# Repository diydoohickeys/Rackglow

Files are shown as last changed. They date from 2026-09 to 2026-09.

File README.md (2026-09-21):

# Rackglow

**An audio-reactive lighting controller for a modular synth case.** A 3.5" touchscreen on the
front panel, WS2812 strips behind the rails, and a spectrum analyser listening to the case's
output — so the lights move with whatever you're patching. Control it from the screen, from a
browser, or from Home Assistant.

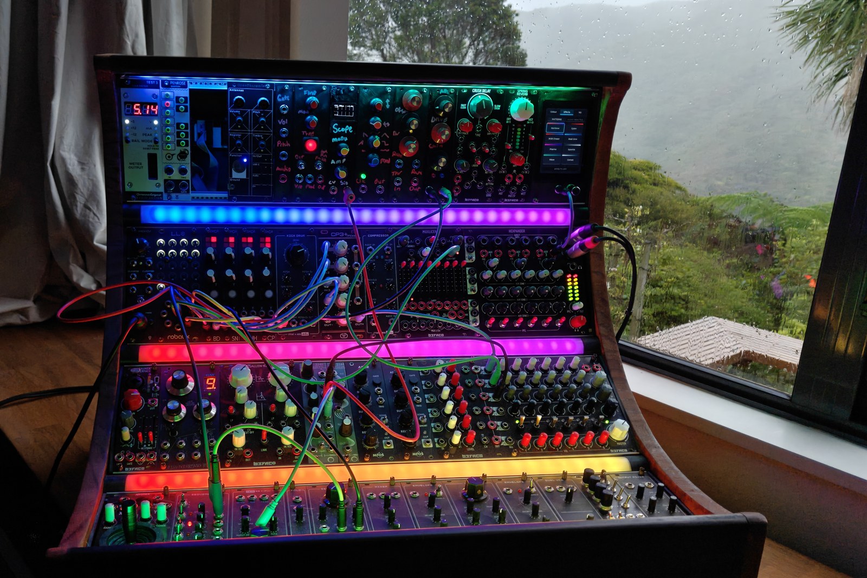
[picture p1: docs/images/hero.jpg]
Rackglow lighting a modular synth case, the strips running a multi-colour effect


https://github.com/user-attachments/assets/42361cac-358a-4347-8153-37f31353e51d

## Features

- **Colour, white and effects** — a colour wheel, a white mode, and 17 effects, 7 of them
  audio-reactive (marked **(A)**: Ice Waves, Purple Rain, Fire, Matrix, VU, Ripple, Confetti).
- **Audio-reactive** — an MSGEQ7 seven-band spectrum analyser drives the (A) effects and a VU mode
  that pumps the strip brightness with the level.
- **Touchscreen UI** — three swipeable tabs: Colour, Effects and a live VU meter.
- **Screensaver** — after an idle timeout the screen hands over to one of five full-screen
  visuals (VU Meter, Waterfall, Aurora, Bloom, Rings); swipe to change, tap to dismiss.
- **Web UI** — the same controls from any browser on your network, plus LED, screensaver and
  Home Assistant settings.
- **Home Assistant** — appears automatically over MQTT as a light (colour, brightness, effects) with
  VU Mode and Screen Sleep switches. No custom integration needed.
- **Screen Sleep** — turn the screen fully off from Home Assistant; tap it to wake.
- **Updates over WiFi** — WiFi setup, a log viewer and firmware updates come from
  [Preflight](https://github.com/diydoohickeys/Preflight-Arduino).

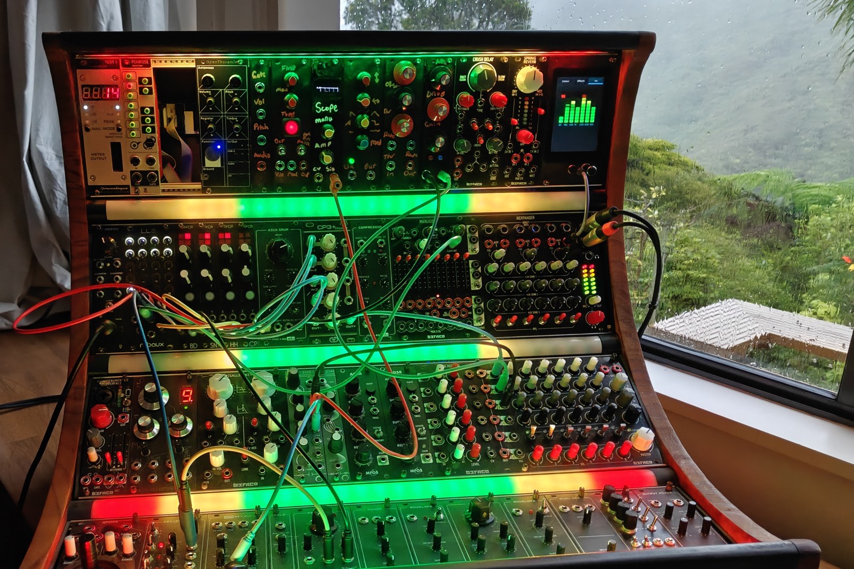
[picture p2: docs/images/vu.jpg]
VU mode running: the strips tracking the case's output, green through red


| Colour | Effects | VU |
|---|---|---|
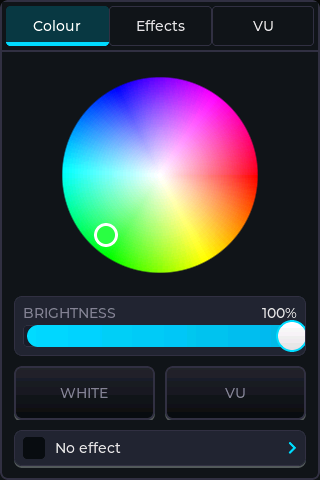
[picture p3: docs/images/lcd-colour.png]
Colour tab
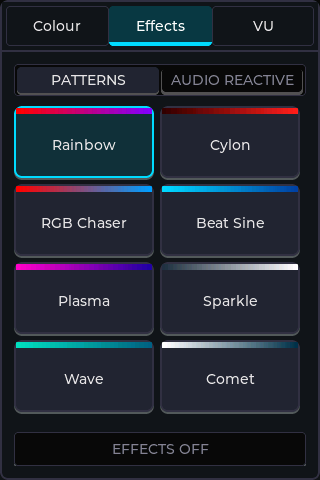
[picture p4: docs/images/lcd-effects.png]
Effects tab
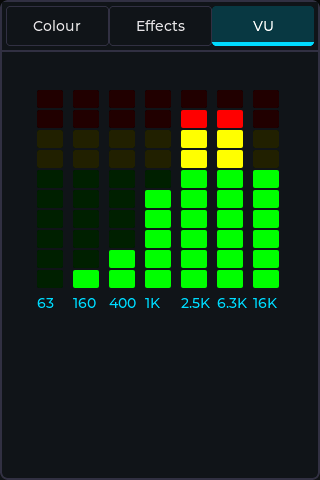
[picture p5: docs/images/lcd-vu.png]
VU tab
|  |  |  |

| VU Meter | Waterfall | Aurora | Bloom | Rings |
|---|---|---|---|---|
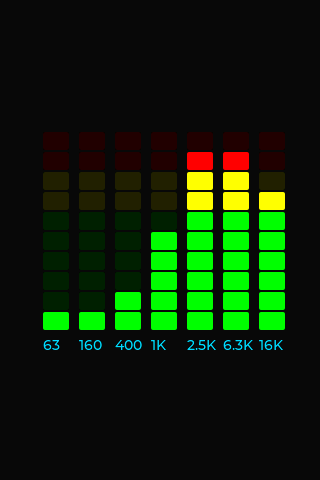
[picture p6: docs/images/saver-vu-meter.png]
VU Meter
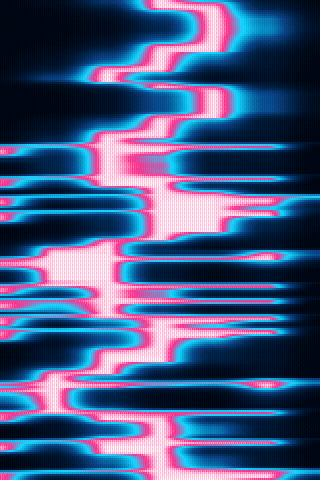
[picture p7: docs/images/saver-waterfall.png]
Waterfall
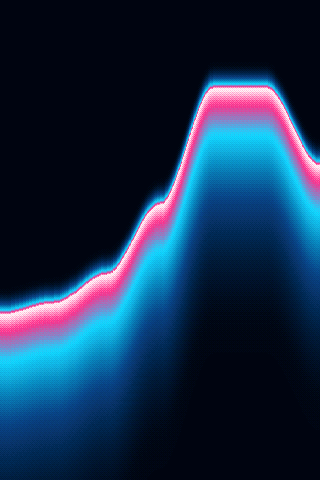
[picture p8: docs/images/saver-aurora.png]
Aurora
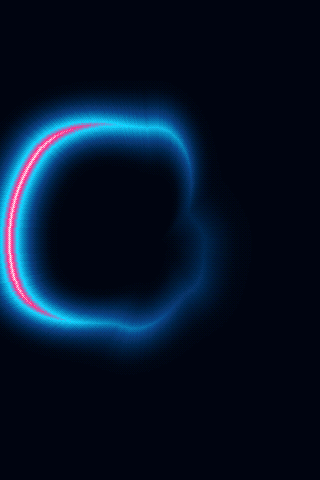
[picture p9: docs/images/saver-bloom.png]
Bloom
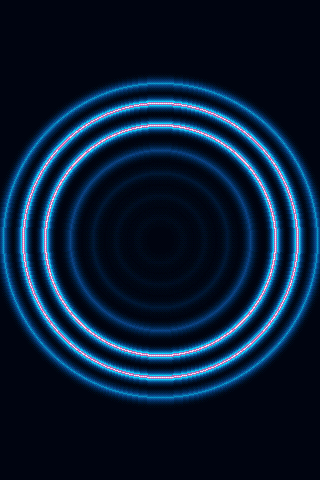
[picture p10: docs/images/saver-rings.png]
Rings
|  |  |  |  |  |

## Hardware

Everything sits behind a 3D-printed panel: the board, and a scrap of protoboard carrying an MSGEQ7
and a handful of passives. There's no custom PCB to order. The panel's CAD and printable files are
in [`hardware/printed/`](hardware/printed) — four parts as STLs, a STEP and the Fusion source.
Standard slicer defaults; only the plug cover needs supports.

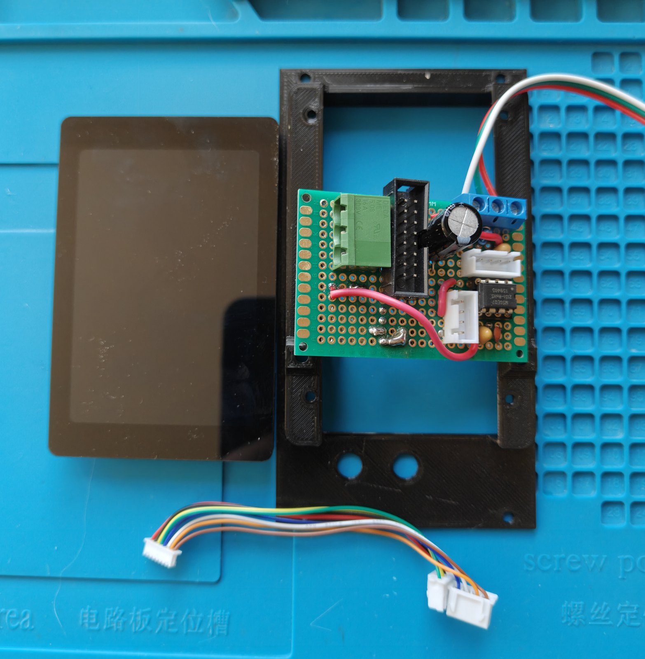
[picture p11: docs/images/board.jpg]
The board, the protoboard and the printed panel, before assembly


| Part | Qty | Notes |
|---|---|---|
| [WT32-SC01 Plus](https://en.wireless-tag.com/product-item-26.html) | 1 | ESP32-S3, 8 MB flash, QSPI PSRAM, 3.5" 320×480 ST7796 touchscreen |
| MSGEQ7 | 1 | Seven-band graphic equaliser, DIP-8. A socket is worth it |
| WS2812 / WS2812B strips | — | Equal-length strips on one data line. The builds here are 5 × 29 and 3 × 29 LEDs |
| A10k potentiometer | 1 | Front-panel input attenuator (audio taper) |
| 3.5 mm jack | 1 | Audio in |
| 22 kΩ, 330 Ω resistors | 1 each | Audio input; WS2812 data line |
| 200 kΩ resistor | 1 | MSGEQ7 clock |
| 0.01 µF, 33 pF, 2 × 0.1 µF | | MSGEQ7 input, clock and decoupling |
| 1000 µF electrolytic, 6.3 V+ | 1 | Across 5 V at the LED terminal |
| Screw terminals, 2- and 3-way | 1 each | 5 V input; LED output |
| 10-pin IDC header | 1 | Eurorack bus power (optional, see below) |
| Protoboard, hook-up wire, JST connectors | | |
| 3D-printed parts | 4 | Panel, LED holder and two covers: [`hardware/printed/`](hardware/printed) |
| 5 V supply for the strips | 1 | Roughly 60 mA per LED at full white. Separate from the case's Eurorack supply |

### Wiring

Wiring diagram

Everything connects to the board's **Extended IO header**, which also carries +5 V and GND. These
are the only GPIOs the WT32-SC01 Plus breaks out; the rest drive the display and touch.

| Header pin | GPIO | Connect to |
|---|---|---|
| EXT_IO1 | 10 | WS2812 data, through the 330 Ω resistor |
| EXT_IO3 | 12 | MSGEQ7 OUT (pin 3) |
| EXT_IO4 | 13 | MSGEQ7 STROBE (pin 4) |
| EXT_IO6 | 21 | MSGEQ7 RESET (pin 7) |
| EXT_IO2, EXT_IO5 | 11, 14 | free |

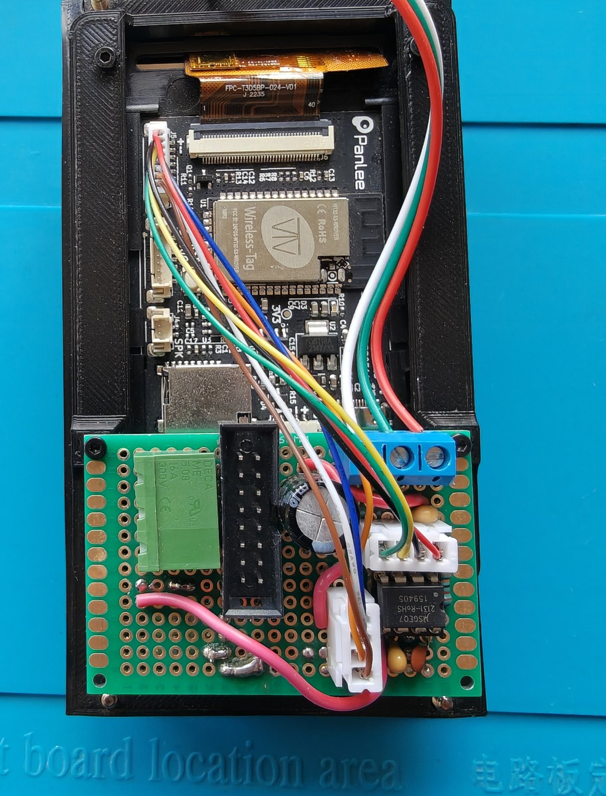
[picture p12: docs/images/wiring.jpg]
The loom from the Extended IO header down to the MSGEQ7 protoboard


**The MSGEQ7 circuit is the datasheet's Typical Application**, unchanged: 22 kΩ and 0.01 µF into IN,
0.1 µF on VDD, another 0.1 µF on pin 6 (the chip's internal 2.5 V reference), and the clock set by
200 kΩ from CKIN up to VDD with 33 pF from CKIN down to ground. Full schematic:
[`hardware/rackglow.pdf`](hardware/rackglow.pdf), editable in KiCad as
[`hardware/rackglow.kicad_sch`](hardware/rackglow.kicad_sch).

**Audio in.** The jack takes a Eurorack-level signal — an FX send, in this build — which is around
10 Vpp, while the MSGEQ7 wants roughly 0.1–0.3 Vpp. The front-panel pot does that attenuation: turn
it up until the loudest passage just reaches the top band without pinning, then back off slightly.
Line level works too, with the pot further up.

**Power.** The panel and the strips are fed separately — the panel draws very little, the strips
draw a lot.

| | Feeds | Notes |
|---|---|---|
| J3 · Eurorack 10-pin bus header | the panel | +5 V and GND from the case's bus board |
| J4 · 5 V screw terminal | the panel, the strips, or both | An external supply |

⚠ **Don't run the strips from a Eurorack 5 V rail.** 145 LEDs at full white can ask for several amps,
far more than those rails are built for. Give the strips their own 5 V supply, sized for roughly
60 mA per LED at full white, and share ground with the board.

What that looks like if you get it wrong: **oscillator pitch drifting as you turn the lights up.**
The strips load the rail, the rail sags, and everything running off it goes with it. That symptom is
what put the second supply in this build — and it reads as a synth fault, not a lighting one.

The reference build uses **two supplies**: the case's Eurorack bus powers the panel through J3, and
a second 5 V supply drives the LED strips alone. One supply through J4 works too, if it is sized for
the strips plus the board.

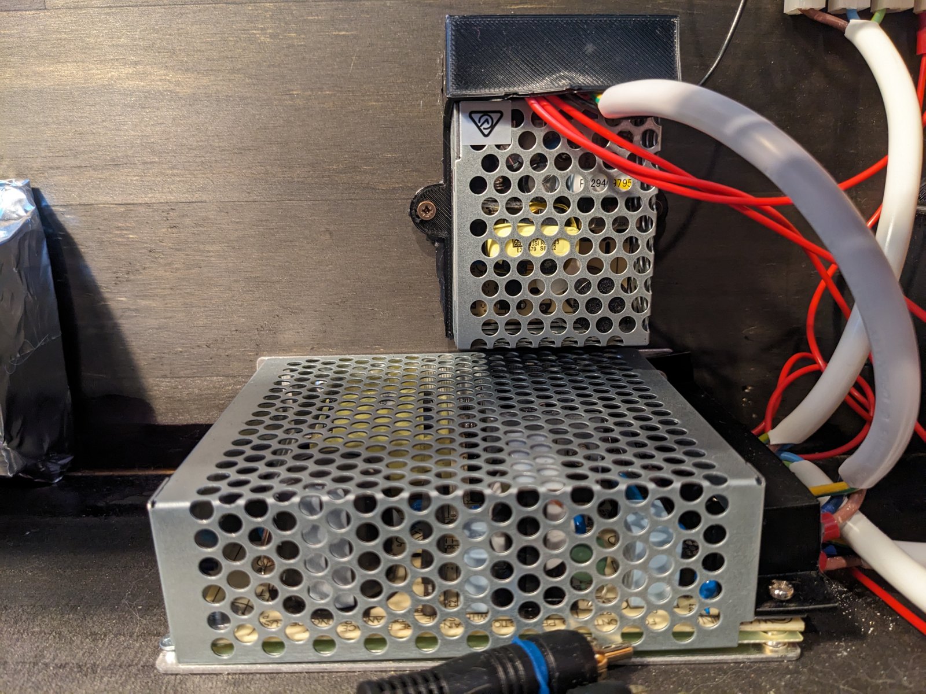
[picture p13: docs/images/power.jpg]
The case's supplies: Eurorack on top, the strips' own 5 V below


**Strip layout.** Strips are daisy-chained on the one data line and treated as equal-length rows.
Alternate strips run in opposite directions (serpentine), which is how they chain naturally behind a
rail. Set the strip count and LEDs per strip under **LED Config** in the web UI.

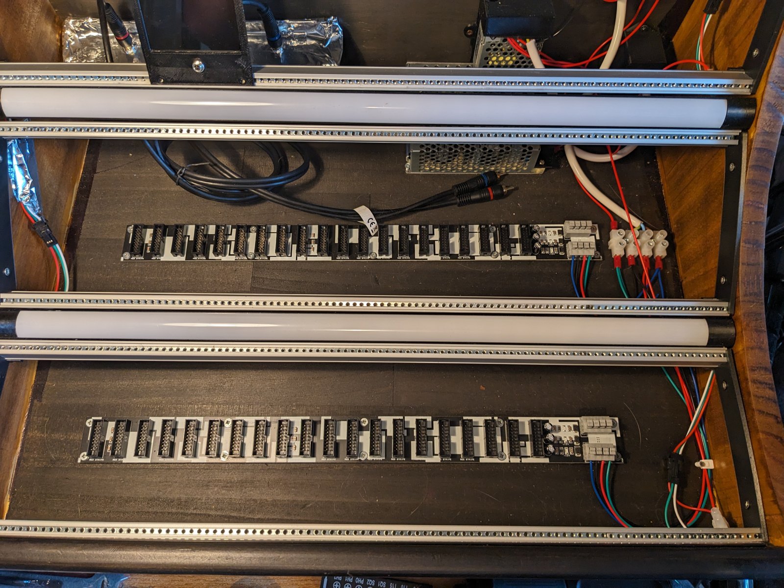
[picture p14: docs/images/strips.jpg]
Strips in aluminium channels between the rails, chained row to row


## Install

### From your browser (easiest)

1. Open **[diydoohickeys.github.io/Rackglow](https://diydoohickeys.github.io/Rackglow/)** in desktop
   Chrome or Edge. Firefox, Safari and phones don't support Web Serial.
2. Plug the board in over USB-C and click **Install**. No button to hold — the board is put into
   download mode over the USB connection.
3. The install erases the board, so it starts fresh.

### First-time setup

1. On first boot Rackglow opens a WiFi network called **`Rackglow-Setup`**
   (password `rackglow123`).
2. Join it from your phone. The setup page opens by itself; if it doesn't, browse to
   `192.168.4.1`.
3. Pick your WiFi network, enter its password and a device name, and save. Rackglow restarts and
   joins your network.
4. Open **`http://rackglow.local`** (or the IP address shown on the screen) and set the strip
   layout under **LED Config**.

### Updating

Download `firmware.bin` from the [latest release](https://github.com/diydoohickeys/Rackglow/releases/latest)
and upload it at **`http://rackglow.local/update`**. Settings are kept.

## Web UI

| Controls | Audio Reactive |
|---|---|
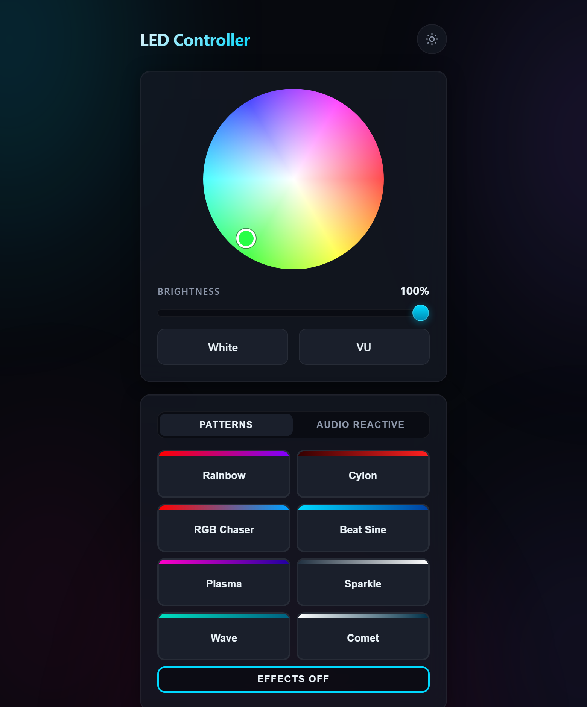
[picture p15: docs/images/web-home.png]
Web UI home
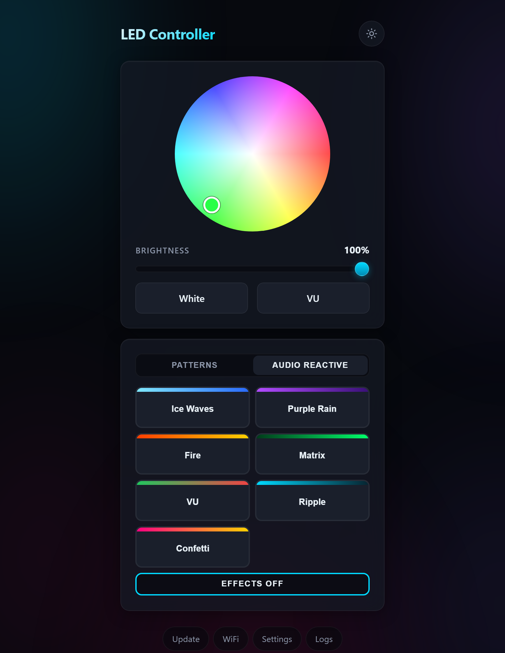
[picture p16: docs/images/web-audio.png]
Audio reactive effects
|  |  |

**LED Config** holds the strip layout, the screensaver and the Home Assistant settings, plus a
screenshot tool for the panel.

| Screensaver + Home Assistant | LED strips |
|---|---|
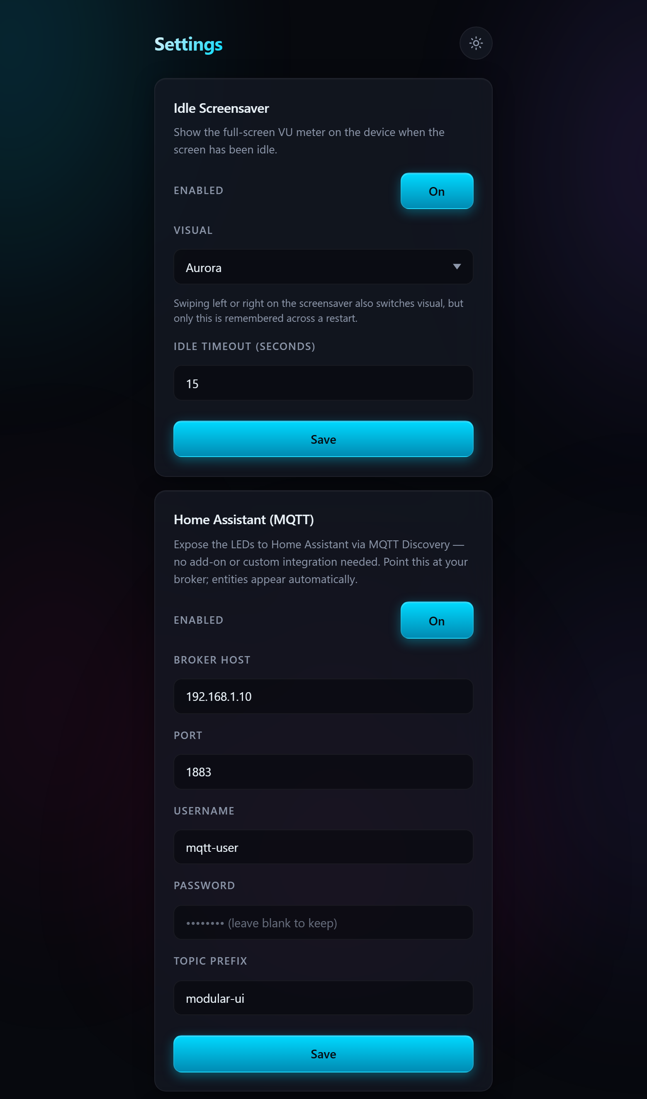
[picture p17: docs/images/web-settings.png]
Settings
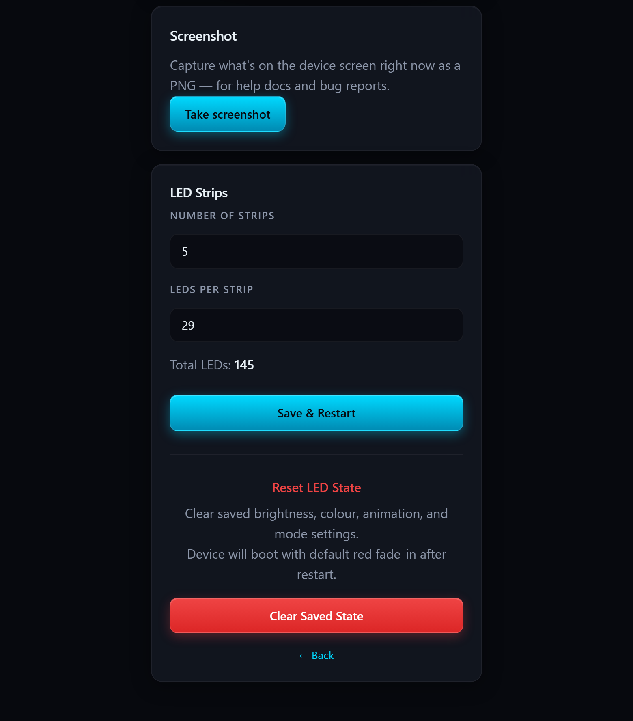
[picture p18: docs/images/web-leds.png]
LED settings
|  |  |

`http://rackglow.local/logs` shows the device log — the first place to look when something isn't
working.

## Home Assistant

Rackglow talks to Home Assistant over MQTT and announces itself using MQTT discovery. You need an
MQTT broker; if you don't already run one, use the **Mosquitto broker** app (formerly add-on).

### 1. Install the broker

In Home Assistant go to **Settings → Apps**, install **Mosquitto broker** and start it. Home
Assistant offers to set up the MQTT integration once it's running — accept it.

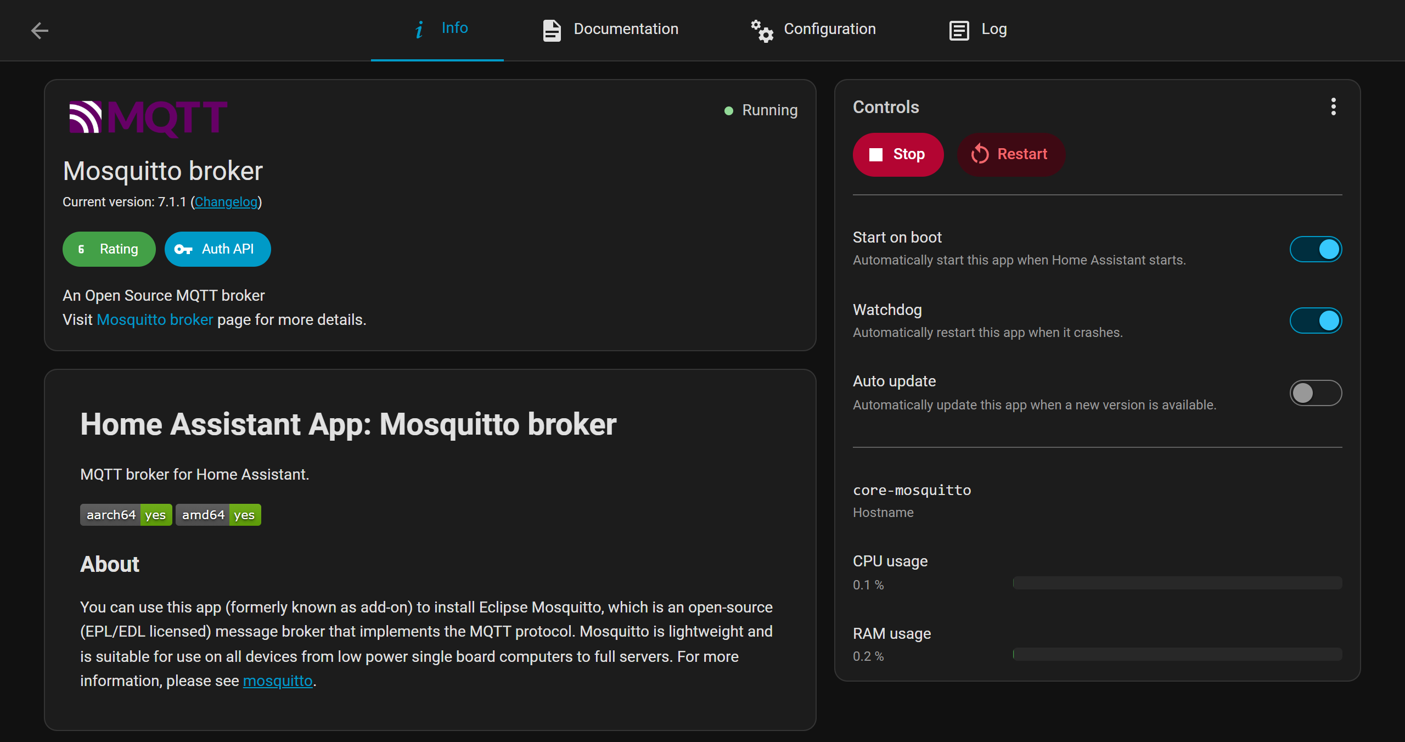
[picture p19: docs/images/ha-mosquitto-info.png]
Mosquitto broker app


### 2. Create a login for Rackglow

Give Rackglow its own broker login rather than a Home Assistant user. Rackglow stores the password
on the device, and a broker-only login can't be used to sign in to Home Assistant itself.

1. Open the Mosquitto broker's **Configuration** tab.
2. Under **Logins** click **Add**, enter a username (e.g. `rackglow`) and a password, and click
   **Add**.

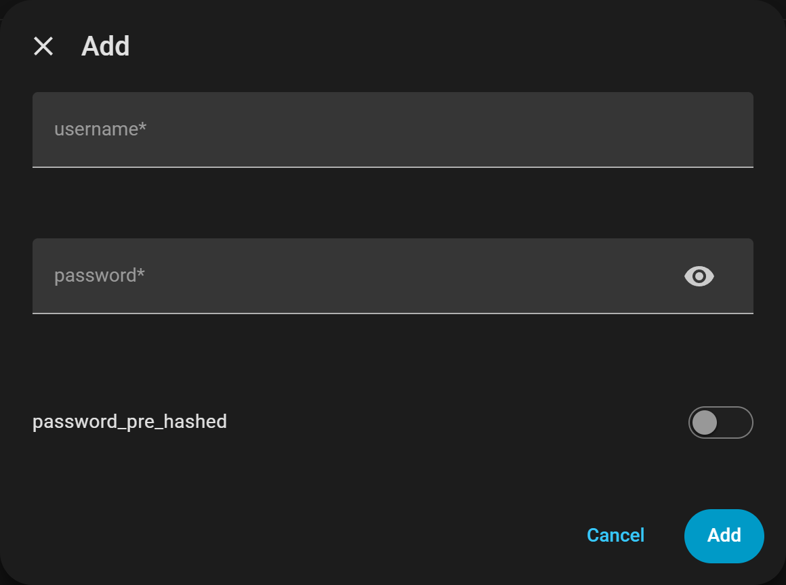
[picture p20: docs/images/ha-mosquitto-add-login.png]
Add a login
   

3. Scroll to the bottom of the **Options** card and click its **Save** — it's the button at the end
   of that card, not the one under Network. Accept the offer to restart the broker.

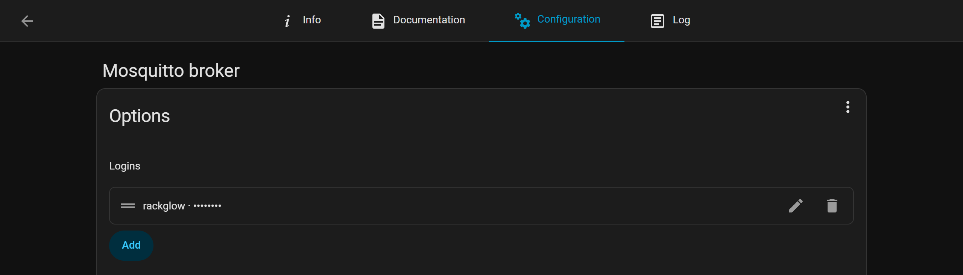
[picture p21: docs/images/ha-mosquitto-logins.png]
Saved login
   

### 3. Connect Rackglow

In Rackglow's web UI open **LED Config → Home Assistant MQTT**, set **Enabled** to On and enter:

| Field | Value |
|---|---|
| Broker Host | Your Home Assistant's IP address (e.g. `192.168.1.20`) |
| Port | `1883` |
| Username / Password | The login from step 2 |

Save. Within a few seconds Rackglow appears under **Settings → Devices & services → MQTT**:

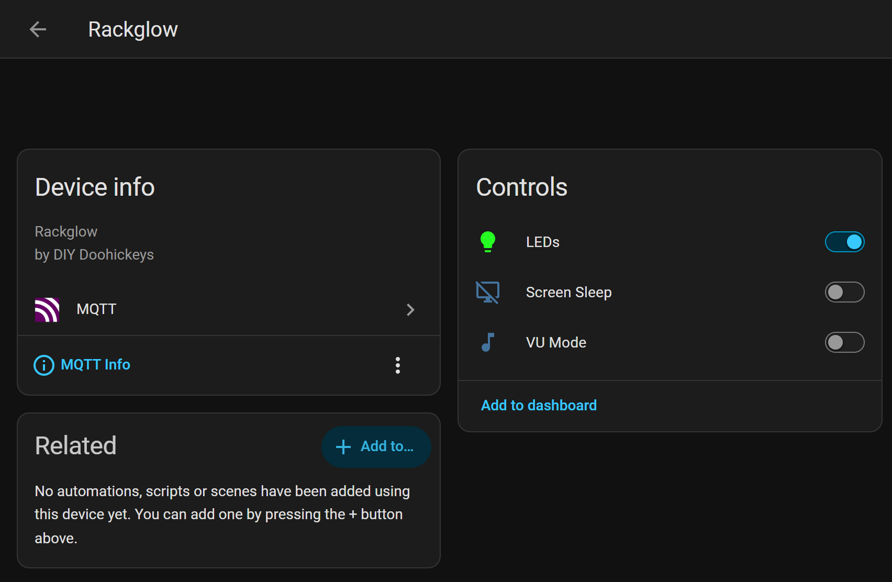
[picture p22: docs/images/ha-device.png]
Rackglow in Home Assistant


| Colour | Effects |
|---|---|
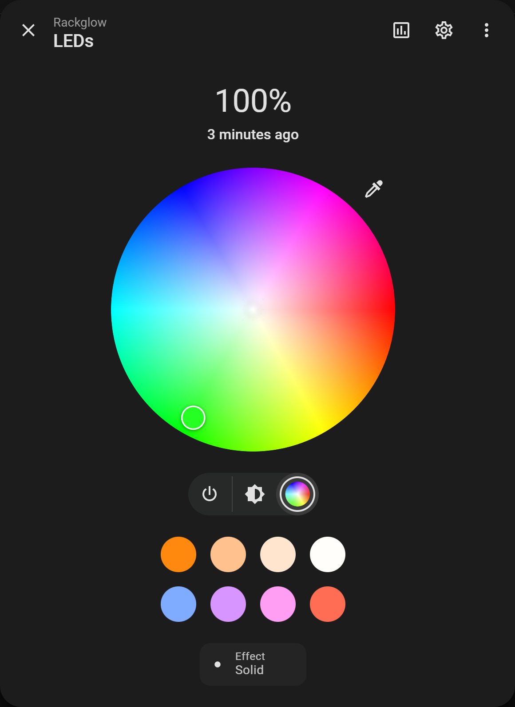
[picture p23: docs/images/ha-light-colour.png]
Light colour wheel
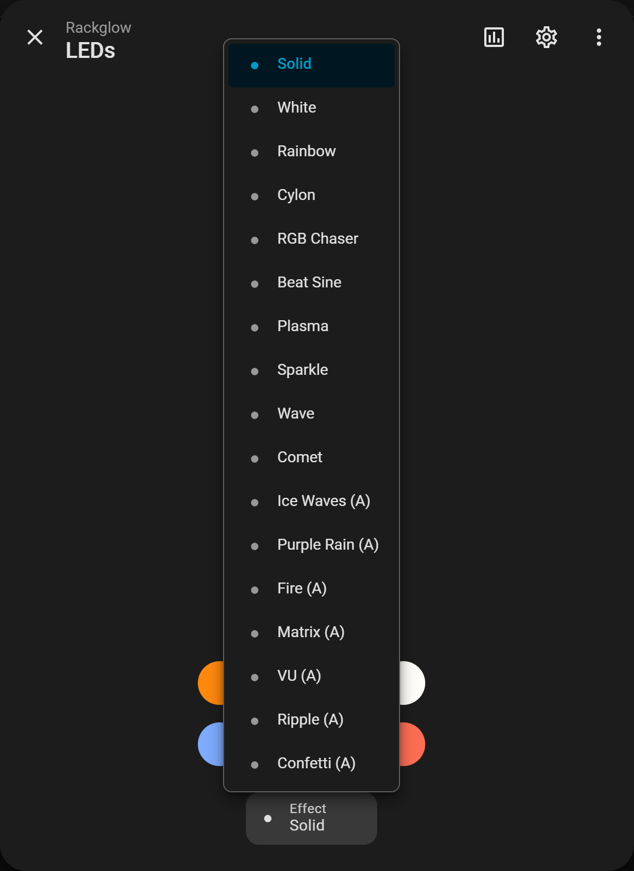
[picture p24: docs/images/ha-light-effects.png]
Effect list
|  |  |

| Entity | What it does |
|---|---|
| `light.rackglow_leds` | On/off, brightness, colour, and every effect by name |
| `switch.rackglow_vu_mode` | Brightness follows the audio level |
| `switch.rackglow_screen_sleep` | Screen fully off. Tapping the screen wakes it and turns this back off |

**Not connecting?** `http://rackglow.local/logs` says why: `username or password rejected`,
`cannot reach` (wrong host or port), or a hostname that won't resolve. Use the IP address rather
than `homeassistant.local`.

## Building from source

Built with [PlatformIO](https://platformio.org) on the Arduino framework (the pioarduino platform,
pinned in `platformio.ini`). You also need [Node.js](https://nodejs.org) 20+, because the web UI is
built during the firmware build.

```bash
pio run -t upload
```

- **The web UI is part of the firmware image.** `build_web.py` runs Vite, gzips the bundle and
  compiles it into the binary, so there's no filesystem to upload and a firmware update always
  carries the matching UI.
- **Web UI development:** `cd web_src && ESP32_HOST=192.168.x.x npm run dev` serves the Vue source
  locally and proxies to a running device. Use the IP: Vite can't resolve `rackglow.local`.
- **Partitions:** two 4 MB app slots for OTA, plus NVS for settings. No data partition.

### Pin notes for hardware changes

GPIO 10 is the only ADC1 pin on the Extended IO header. ADC2 (GPIO 11–20) is unreliable while
WiFi is active, which is why the MSGEQ7's analog read on GPIO 12 pauses during an OTA update. A
different analog audio input needs GPIO 10 (moving the LED data elsewhere) or an I2S ADC — retiring
the MSGEQ7 frees GPIO 12, 13 and 21, enough for I2S.

## License

MIT — see [LICENSE](LICENSE). Third-party components and their licences are listed in
[THIRD-PARTY-NOTICES.md](THIRD-PARTY-NOTICES.md).

Made by [DIY Doohickeys](https://diydoohickeys.com).

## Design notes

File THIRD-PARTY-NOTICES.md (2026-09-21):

# Third-party notices — Rackglow

This project is MIT licensed (see `LICENSE`). Listed below is the third-party software
distributed with, or linked into, the firmware, each of which remains under its own
licence.

Versions and licences were read from the **resolved** packages in `.pio/libdeps/` and
`web_src/node_modules/`, not from memory. `lib_deps` pins its direct dependencies
exactly, but AsyncTCP and ESPAsyncWebServer arrive through Preflight's own version
ranges and can move — re-check this table before any release.

## Linked into the firmware

| Dependency | Version | Licence |
|---|---|---|
| [ArduinoJson](https://github.com/bblanchon/ArduinoJson) | 7.4.3 | MIT |
| [AsyncTCP](https://github.com/ESP32Async/AsyncTCP) | 3.5.0 | **LGPL-3.0** |
| [ESPAsyncWebServer](https://github.com/ESP32Async/ESPAsyncWebServer) | 3.12.1 | **LGPL-3.0** |
| [LovyanGFX](https://github.com/lovyan03/LovyanGFX) | 1.2.28 | MIT **and** FreeBSD (BSD-2-Clause) — see note |
| [LVGL](https://github.com/lvgl/lvgl) | 9.5.0 | MIT |
| Montserrat (LVGL built-in fonts) | with LVGL 9.5.0 | **OFL-1.1** — see note |
| [Preflight](https://github.com/diydoohickeys/Preflight-Arduino) | 1.0.0 | MIT |
| `lib/led_strip` (vendored) | Espressif, 2022–2024 | Apache-2.0 |
| [arduino-esp32](https://github.com/espressif/arduino-esp32) (via the pioarduino platform) | per `platformio.ini` | LGPL-2.1, over ESP-IDF (Apache-2.0) |

## Bundled in the web UI

| Dependency | Version | Licence |
|---|---|---|
| [Vue](https://github.com/vuejs/core) | 3.5.43 | MIT |

The Vue runtime is compiled into the single `app.js` that `build_web.py` embeds in the
firmware image, so it ships in the binary rather than being fetched at runtime. Vite and
`@vitejs/plugin-vue` are build-time only and are not distributed.

## Notes

**LovyanGFX** ships one `license.txt` covering several origins: the library's own code
under the FreeBSD (BSD-2-Clause) licence, plus retained headers from Adafruit's
`Adafruit_ILI9341` (MIT) and Bodmer's TFT_eSPI (FreeBSD). All of it must travel with any
redistribution — see that file in the package.

**Montserrat** is embedded as LVGL bitmap fonts rather than as font files.
`include/lv_conf.h` enables sizes 10, 12, 14, 18, 22 and 32, so the SIL Open Font Licence
1.1 applies to the firmware image. It is a permissive licence; its only real condition
here is that the font's name not be used to promote derivative fonts.

**LGPL-3.0 (AsyncTCP, ESPAsyncWebServer)** and **LGPL-2.1 (arduino-esp32)** are the only
copyleft licences in the set. Both are satisfied by distributing this firmware's own
source — which is public and MIT — alongside the unmodified upstream sources, and neither
library is modified here.

**The MSGEQ7 driver** (`include/audio/Msgeq7.h`, `src/audio/Msgeq7.cpp`) is original work,
written from the MSGEQ7 datasheet's timing table. It replaced a third-party library that
stated no licence anywhere, and shares no code with it.

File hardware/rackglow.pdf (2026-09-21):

1 | 2 | 3 | 4 | 5 | 6
1 | 2 | 3 | 4 | 5 | 6

AB

C

D

AB

C

D Date:

Size: A4 | Rev:
KiCad E.D.A. 10.0.4 | Id: 1/1

## Title: Rackglow

File: rackglow.kicad_sch

### Sheet: /

### DIY Doohickeys

Audio-reactive lighting controller for a modular synth case diydoohickeys.com

1 2 C2

0.1uF

TIP | 1
SLEEVE | 2

J1

Audio in (3.5 mm) | 1 2 | C3
0.1uF +5V | 1 GND | 2

J4

5 V supply in

1 2 C4

33pF CCW

1 WIPER 2 CW

3 RV1

A10k | 1 | 2 C1
0.01uF | VDD

## 1 VSS

2 OUT 3

STROBE 4

IN 5 | GND | 6 RESET 7 | CKIN | 8 U1 MSGEQ7
1 2 R2
200k 1 | 2
3 | 4
5 | 6
7 | 8
9 | 10

J3

Eurorack bus (2x5) | 1 | 2 R1
22k | 1 2 | C5
1000uF 6.3V 5V 1 | GND 2 | GPIO12/IO3 3 | GPIO13/IO4 4 | GPIO21/IO6 5 | GPIO10/IO1 | 6 U2WT32-SC01 Plus | +5V 1 | DATA 2 | GND 3

J2

LED strips 1 | 2 R3
330R RESET STROBE | STROBE RESET MSGEQ_OUT | MSGEQ_OUT Rackglow - WT32-SC01 Plus + MSGEQ7 spectrum analyser

J1 takes a Eurorack-level FX send (~10 Vpp). The MSGEQ7 wants roughly 0.1-0.3 Vpp, so RV1 on the front panel attenuates: set it so the loudest passage just reaches the top band without pinning.

Strip layout is set in the web UI (strips x LEDs per strip), chained

on one data line with alternate strips reversed. POWER - two options, fit one: J3 | Eurorack 10-pin bus: +5V and GND only. Confirm which pins carry them on your bus board before wiring. J4 | External 5 V supply (screw terminal). The LEDs are the load that matters: 145 LEDs (5 x 29) draw several amps at full white, far beyond a Eurorack 5 V rail. Big case: external supply on J4 feeds both the board and the LEDs. Small case (3 x 29): same rule.

MSGEQ7 support parts are the datasheet Typical Application: 22k + 0.01uF into IN, 0.1uF on VDD (CD) and on pin 6 (CG), 200k from CKIN up to VDD and 33pF from CKIN

down to GND (165 kHz clock). J1

Audio in (3.5 mm) TIP | 1
SLEEVE | 2 | U1 MSGEQ7 | VDD

## 1 VSS

2 OUT 3

STROBE 4

IN 5 | GND | 6 RESET 7 | CKIN | 8 RV1

A10k CCW

1 WIPER 2 CW

3

U2WT32-SC01 Plus 5V 1 | GND 2 | GPIO12/IO3 3 | GPIO13/IO4 4 | GPIO21/IO6 5 | GPIO10/IO1 | 6

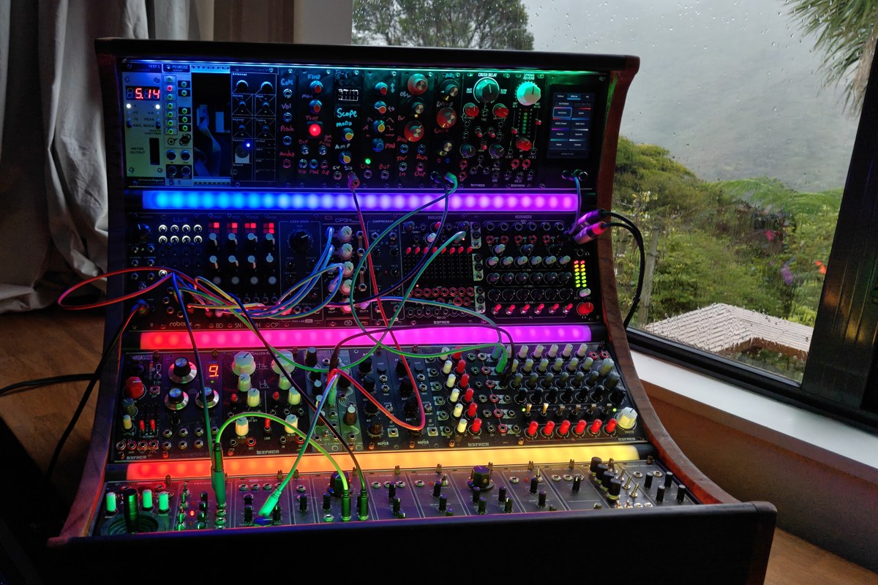
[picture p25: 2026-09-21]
docs/images/case-glow.jpg

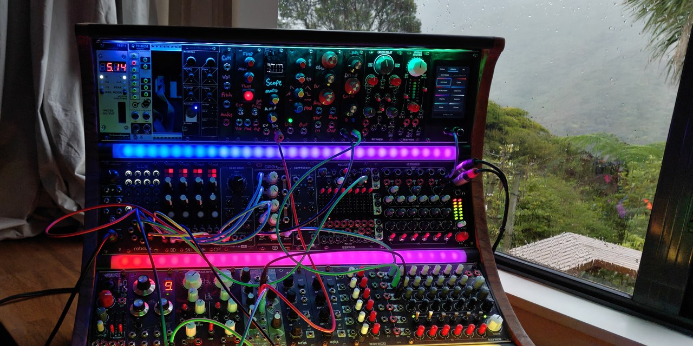
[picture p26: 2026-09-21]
docs/images/social-preview.jpg

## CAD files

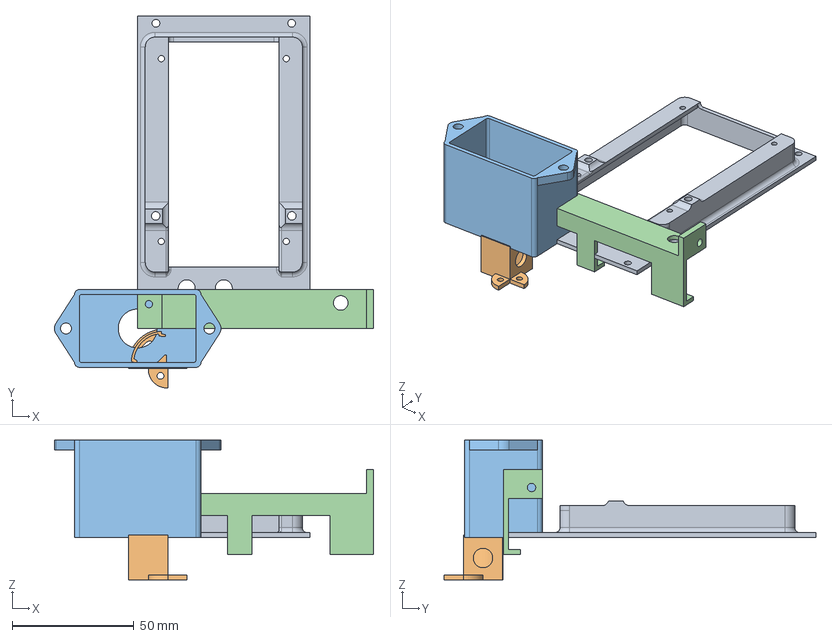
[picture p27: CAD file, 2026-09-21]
hardware/printed/rackglow.step
131.2 x 153.0 x 57.5 mm
Control Panel
Curved Light Holder
Plug Cover
Power Cover

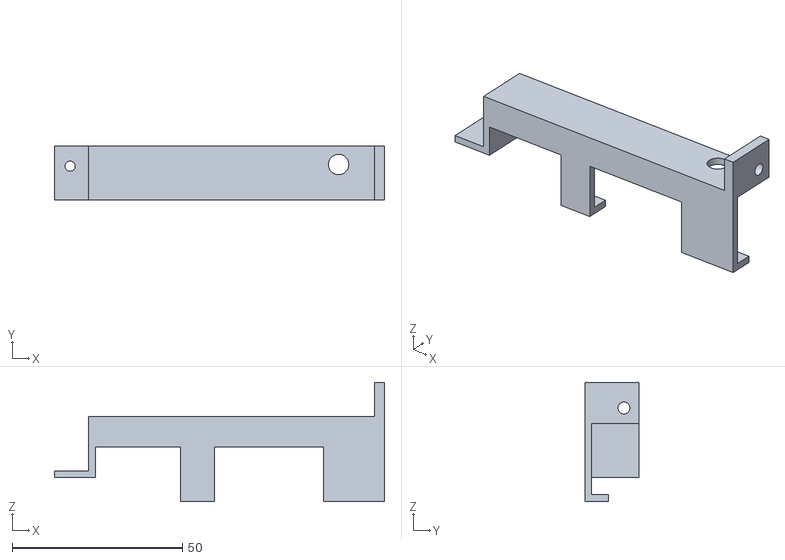
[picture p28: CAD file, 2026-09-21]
hardware/printed/power-cover.stl
97.0 x 16.0 x 35.0

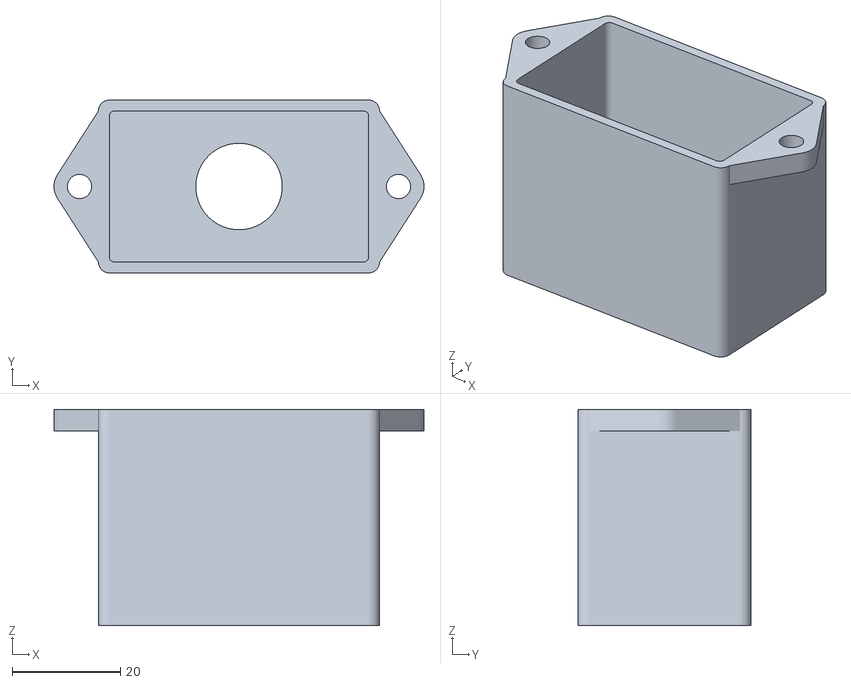
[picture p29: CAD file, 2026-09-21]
hardware/printed/plug-cover.stl
68.5 x 32.0 x 40.0

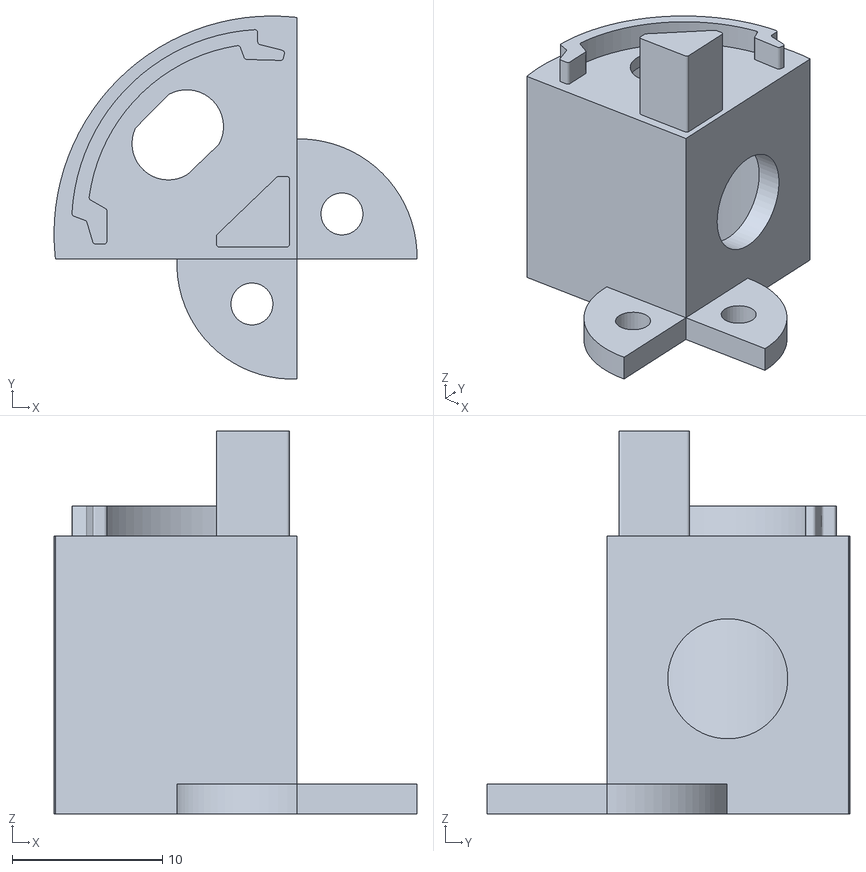
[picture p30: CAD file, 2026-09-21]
hardware/printed/curved-light-holder.stl
24.2 x 24.2 x 25.5

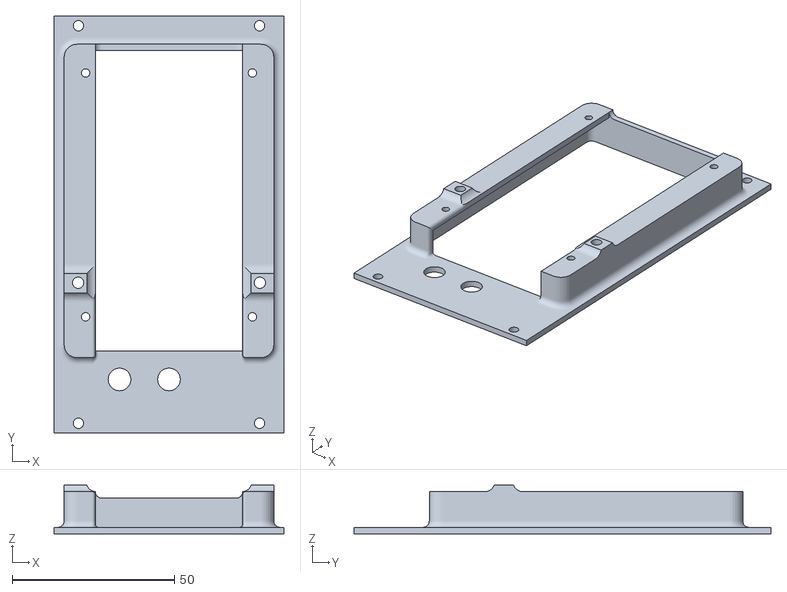
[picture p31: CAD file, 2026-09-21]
hardware/printed/control-panel.stl
70.8 x 128.5 x 15.0

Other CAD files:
hardware/printed/rackglow.f3d

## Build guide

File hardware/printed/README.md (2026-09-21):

# Printed parts

Four parts: the Eurorack front panel that carries the WT32-SC01 Plus, the MSGEQ7 protoboard, the
pot and the jack — plus a holder for the LED strip and two covers.

| File | Part | Size |
|---|---|---|
| `control-panel.stl` | Front panel, 14 HP × 3U | 70.8 × 128.5 × 15.0 mm |
| `curved-light-holder.stl` | LED strip holder | 24.2 × 24.2 × 25.5 mm |
| `plug-cover.stl` | Plug cover | 68.5 × 32.0 × 40.0 mm |
| `power-cover.stl` | Power cover | 97.0 × 16.0 × 35.0 mm |
| `rackglow.step` | All four parts, neutral CAD | opens in any package |
| `rackglow.f3d` | Fusion 360 source, all four parts | Fusion only |

Standard slicer defaults print all of it. **Only `plug-cover` needs supports**; the rest print
without.

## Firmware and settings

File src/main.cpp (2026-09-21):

#include "rackglow.h"
#include "ui/UIManager.h"
#include "WifiBootManager.h"
#include "led/LEDManager.h"
#include "WebUIManager.h"
#include "MqttManager.h"
#include "audio/AudioTask.h"
#include <OTAManager.h>
#include <Logger.h>
#include <esp_system.h>

// Global manager instances
extern UIManager* g_uiManager;
extern LEDManager* g_ledManager;
extern WebUIManager* g_webUIManager;
extern WifiBootManager* g_wifiBootManager;
extern OTAManager* g_otaManager;
extern MqttManager* g_mqttManager;

// Why the last boot happened. On an unexplained reboot this one line separates a
// firmware panic from a task watchdog from a brownout (145 LEDs can pull enough
// to sag a weak supply) — guessing between those costs far more than logging it.
static const char* resetReasonName(esp_reset_reason_t reason) {
    switch (reason) {
        case ESP_RST_POWERON:   return "power-on";
        case ESP_RST_EXT:       return "external pin";
        case ESP_RST_SW:        return "software restart";
        case ESP_RST_PANIC:     return "PANIC / exception";
        case ESP_RST_INT_WDT:   return "interrupt watchdog";
        case ESP_RST_TASK_WDT:  return "task watchdog";
        case ESP_RST_WDT:       return "other watchdog";
        case ESP_RST_DEEPSLEEP: return "deep sleep wake";
        case ESP_RST_BROWNOUT:  return "BROWNOUT (supply sag)";
        case ESP_RST_SDIO:      return "SDIO";
        default:                return "unknown";
    }
}

// Global restart flag for async operations
bool g_restartRequested = false;
unsigned long g_restartTime = 0;

void setup()
{
    Serial.begin(115200);
    delay(1000);

    // Initialize logger early
    Logger.begin(200, true, true);
    Logger.info("Rackglow starting...");
    Logger.info("Reset reason: %s", resetReasonName(esp_reset_reason()));

    // PSRAM diagnostic — the full-screen visualiser canvas needs it. If found=0
    // here, the platformio.ini memory_type doesn't match the module's PSRAM.
    Logger.info("PSRAM: found=%d, size=%u bytes, free=%u bytes",
                psramFound() ? 1 : 0,
                (unsigned)ESP.getPsramSize(),
                (unsigned)ESP.getFreePsram());

    // Initialize UI Manager (screen only at first)
    g_uiManager = new UIManager();
    g_uiManager->initializeScreen();

    // Initialize network (WiFi + boot screen)
    g_wifiBootManager = new WifiBootManager();
    g_wifiBootManager->initialize();

    // Initialize full UI and LEDs if not in setup mode
    if (!g_wifiBootManager->isInSetupMode()) {
        // Boot screen goes FIRST, before the UI allocates. Nothing renders between
        // here and startRenderTask() below — no lv_refr_now, and the render task
        // isn't up yet — so the panel simply holds the last flushed boot frame
        // either way, and freeing first means the UI's objects don't land on top
        // of ~24 boot widgets that are about to leave holes under them. LVGL draws
        // into layers taken from that same fixed pool, so its largest free block
        // is a rendering cost, not just a headroom number.
        g_wifiBootManager->setBootStatus("Starting interface");
        g_wifiBootManager->cleanupBootUI();
        UIManager::logLvglMemory("after boot screen freed");
        g_uiManager->initializeUI();

        g_ledManager = new LEDManager();
        g_ledManager->initialize();
    }

    // Initialize WebUI Manager
    g_webUIManager = new WebUIManager(g_wifiBootManager->getWebServer());
    g_webUIManager->initialize();
    Logger.attachWebSocket(g_webUIManager->getWebSocket());

    // Startup sequence (only if not in setup mode)
    if (g_ledManager) {
        g_ledManager->performStartupDispersion();
        g_uiManager->syncWithLEDState();

        // Home Assistant bridge — needs WiFi (connected in normal mode) and the
        // LED manager. Skipped in captive-portal/setup mode along with the rest.
        g_mqttManager = new MqttManager(g_ledManager);
        g_mqttManager->begin();
    }

    // Hand LVGL ownership to the render task — only in normal mode, and only
    // after all startup lv_* (syncWithLEDState) has completed so nothing races
    // the task during boot. In setup mode the boot UI keeps driving LVGL on the
    // loop, so no render task is created.
    if (!g_wifiBootManager->isInSetupMode()) {
        // Audio task first so frames are flowing before the render task and LED
        // animations start pulling from g_audioBus.
        startAudioTask();
        g_uiManager->startRenderTask();
    }
}

void loop()
{
    // LVGL tick comes from lv_tick_set_cb(millis) registered in
    // UIManager::initializeScreen() — no manual lv_tick_inc here.

    // LVGL ownership:
    //  - Normal mode: the render task owns all lv_* (started at end of setup).
    //    The loop must NOT touch LVGL here — it only runs the non-UI managers.
    //  - Setup mode / no UI manager: no render task, so drive LVGL on the loop
    //    as before to keep the boot UI alive.
    if (!(g_uiManager && g_uiManager->isRenderTaskRunning())) {
        if (g_uiManager) {
            g_uiManager->update();
            if (g_wifiBootManager && g_wifiBootManager->isInSetupMode()) {
                lv_timer_handler();
            }
        } else {
            lv_timer_handler();
        }
    }

    if (g_wifiBootManager) g_wifiBootManager->update();
    if (g_ledManager) g_ledManager->update();
    if (g_webUIManager) g_webUIManager->update();
    if (g_mqttManager) g_mqttManager->update();
    if (g_otaManager) g_otaManager->loop();

    // With the render task owning LVGL, the loop no longer blocks on the flush.
    // LEDManager::update()'s driver_.show() paces us when strips are configured,
    // but yield explicitly so loopTask never 100%-spins core 1 (starving IDLE1)
    // when LEDs are absent. 1 ms cap is far above any LED frame rate.
    if (g_uiManager && g_uiManager->isRenderTaskRunning()) {
        vTaskDelay(1);
    }

    // Handle restart requests
    if (g_restartRequested && g_restartTime == 0) {
        g_restartTime = millis();
    }
    if (g_restartTime > 0 && millis() - g_restartTime > 2000) {
        ESP.restart();
    }
}

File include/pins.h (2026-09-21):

#pragma once

/**
 * @brief Central board pin map for the WT32-SC01 Plus.
 *
 * Single source of truth for every GPIO the firmware drives — referenced by the
 * Display module, LEDManager, and the audio task. This wiring is SETTLED: do not
 * change a value without a hardware reason.
 *
 * ONLY GPIO 10, 11, 12, 13, 14 and 21 leave the board (the Extended IO header),
 * plus GPIO0/TXD0/RXD0 on the debug header. Everything else here is soldered to
 * the panel or the touch controller. GPIO10 is the only ADC1 pin of those, which
 * matters because ADC2 is unusable while WiFi is up. The full header pinout is in
 * CLAUDE.md under "Board: WT32-SC01 Plus breakout". (The PlatformIO `board = esp32-s3-devkitc-1` is just a generic S3
 * target; the real hardware is the SC01 Plus.)
 */
namespace pins {

// --- Display: ST7796 320x480 over an 8-bit 8080 parallel bus (LovyanGFX) ---
constexpr int LCD_WR   = 47;
constexpr int LCD_RD   = -1;
constexpr int LCD_RS   = 0;   // data/command select
constexpr int LCD_D0   = 9;
constexpr int LCD_D1   = 46;
constexpr int LCD_D2   = 3;
constexpr int LCD_D3   = 8;
constexpr int LCD_D4   = 18;
constexpr int LCD_D5   = 17;
constexpr int LCD_D6   = 16;
constexpr int LCD_D7   = 15;
constexpr int LCD_CS   = -1;
constexpr int LCD_RST  = 4;
constexpr int LCD_BUSY = -1;
constexpr int LCD_BL   = 45;  // backlight (PWM)

// --- Touch: FT5x06 capacitive (I2C) ---
constexpr int TOUCH_SDA = 6;
constexpr int TOUCH_SCL = 5;

// --- LED strip data (WS2812, RMT + DMA) ---
constexpr int LED_DATA = 10;

// --- Audio: MSGEQ7 spectrum analyser ---
constexpr int MSGEQ7_STROBE = 13;
constexpr int MSGEQ7_RESET  = 21;
constexpr int MSGEQ7_ANALOG = 12;  // GPIO12 = ADC2 (shared with WiFi — paused during OTA)

}  // namespace pins

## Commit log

2026-09-21 Rackglow: ESP32-S3 audio-reactive LED controller for a modular synth case
    [partitions.csv, rackglow.kicad_sch]
2026-09-21 Add the case-glow photo: website card and GitHub social preview
2026-09-21 Photos: a multi-hue hero, and a VU frame for the audio-reactive section
2026-09-21 Social preview: the multi-hue frame; record the verified video constraints
2026-09-21 Landing card: the multi-hue frame, matching the social preview
2026-09-21 Add the panel's Fusion source
    [rackglow-panel.f3d]
2026-09-21 Printed parts: all four STLs, a STEP and the Fusion source
    [control-panel.step, control-panel.stl, curved-light-holder.stl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]
2026-09-21 STEP: the full four-part assembly
    [control-panel.step, rackglow.step]
2026-10-26 Sign-in, optional HTTPS, MQTT over TLS and faster pages
    - Web UI and API behind Preflight's device password; a 401 sends the page to
    /login and back (deviceFetch)
    - /ws moves onto Preflight's server as WsHub, admitting only signed-in
    clients before the upgrade
    - MQTT over TLS (opt-in, verified against the trusted CA; the toggle swaps
    1883/8883)
    - WiFi AMPDU TX off: some mesh APs drop the first segment of a TCP burst,
    which stalled pages for seconds
    - Dev proxy forwards the per-scheme session cookie; CI and gitignore updates
2026-10-26 CI: pin PlatformIO Core 6.1.19 (6.2 brings SCons 4.11, which breaks the link step)
